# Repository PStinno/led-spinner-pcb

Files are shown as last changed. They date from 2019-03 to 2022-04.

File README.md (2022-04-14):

# led-spinner-pcb
My first two layer PCB, spinning LED effect with no micro-controller or code.



The circuit consists of two 4017 decade counters, connected together to create sixteen sequential outputs. The outputs progress on each clock cycle and loop back to the beginning when the end is reached. Each output is connected to an LED on the perimeter of the PCB. The clock input is connected to a 555 timer IC in an astable configuration. This generates a continous square wave, causing the progression of the outputs and the spinning effect. The momentary push button completes the circuit, so it is only powered when the button is held down.

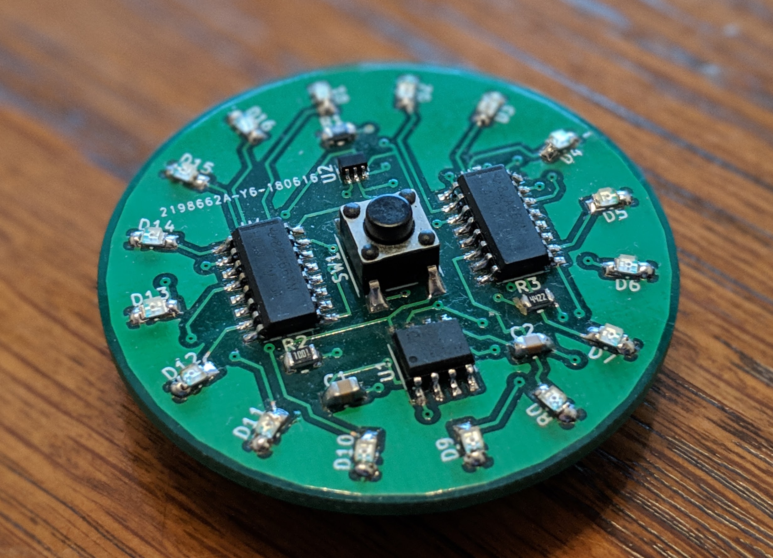
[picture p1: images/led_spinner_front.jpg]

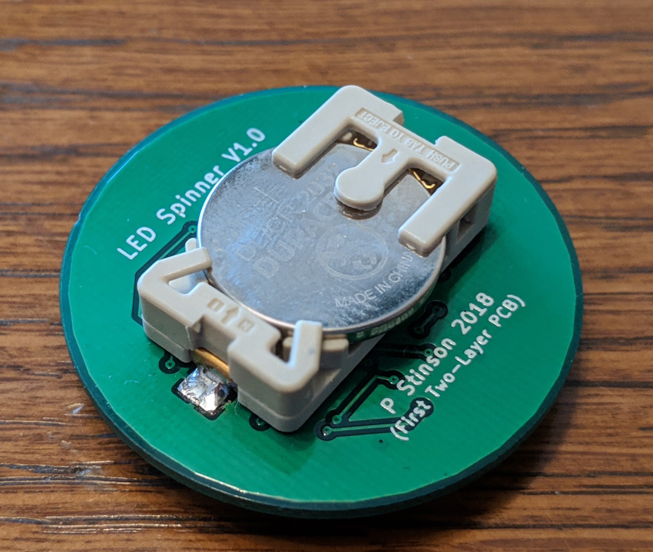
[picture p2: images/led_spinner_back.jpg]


[][cc-by-sa]

[cc-by-sa]: http://creativecommons.org/licenses/by-sa/4.0/
[cc-by-sa-image]: https://licensebuttons.net/l/by-sa/4.0/88x31.png
[cc-by-sa-shield]: https://img.shields.io/badge/License-CC%20BY--SA%204.0-lightgrey.svg

This work is licensed under a [Creative Commons Attribution-ShareAlike 4.0 International License][cc-by-sa].

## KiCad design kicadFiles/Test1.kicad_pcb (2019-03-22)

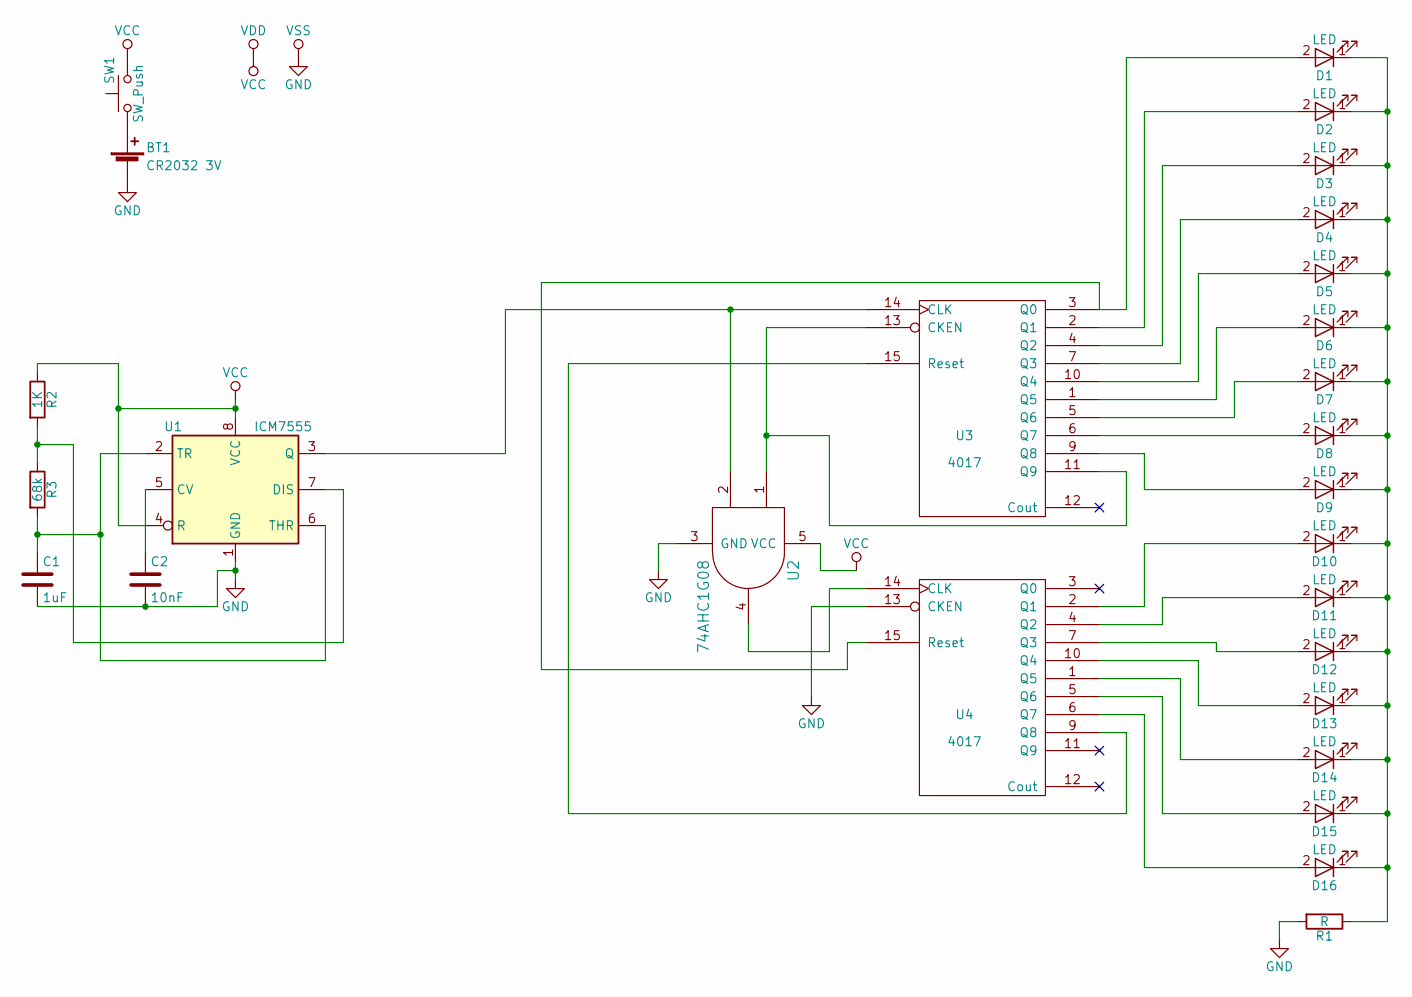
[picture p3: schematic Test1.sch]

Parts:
BT1: CR2032 3V; MPD_BA2032SM
C1: 1uF; C_0805
C2: 10nF; C_0805
D1, D2, D3, D4, D5, D6, D7, D8, D9, D10, D11, D12, D13, D14, D15, D16: LED; LED_0805
R1: R; R_0805
R2: 1K; R_0805
R3: 68k; R_0805
SW1: SW_Push; SW_SPST_PTS645
U1: ICM7555; SOIC-8_3.9x4.9mm_Pitch1.27mm
U2: 74AHC1G08; SOT-353_SC-70-5
U3, U4: 4017; SOIC-16_3.9x9.9mm_Pitch1.27mm

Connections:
GND: BT1.2 (-), C1.2, C2.2, R1.2, U1.1 (GND), U2.3 (GND), U3.8 (VSS), U4.8 (VSS), U4.13 (CKEN)
unnamed: BT1.1 (+), SW1.1
unnamed: C1.1, R3.2, U1.2 (TR), U1.6 (THR)
unnamed: C2.1, U1.5 (CV)
unnamed: D1.1 (K), D2.1 (K), D3.1 (K), D4.1 (K), D5.1 (K), D6.1 (K), D7.1 (K), D8.1 (K), D9.1 (K), D10.1 (K), D11.1 (K), D12.1 (K), D13.1 (K), D14.1 (K), D15.1 (K), D16.1 (K), R1.1
unnamed: D1.2 (A), U3.3 (Q0), U4.15 (Reset)
unnamed: D2.2 (A), U3.2 (Q1)
unnamed: D3.2 (A), U3.4 (Q2)
unnamed: D4.2 (A), U3.7 (Q3)
unnamed: D5.2 (A), U3.10 (Q4)
unnamed: D6.2 (A), U3.1 (Q5)
unnamed: D7.2 (A), U3.5 (Q6)
unnamed: D8.2 (A), U3.6 (Q7)
unnamed: D9.2 (A), U3.9 (Q8)
unnamed: D10.2 (A), U4.2 (Q1)
unnamed: D11.2 (A), U4.4 (Q2)
unnamed: D12.2 (A), U4.7 (Q3)
unnamed: D13.2 (A), U4.10 (Q4)
unnamed: D14.2 (A), U4.1 (Q5)
unnamed: D15.2 (A), U4.5 (Q6)
unnamed: D16.2 (A), U4.6 (Q7)
unnamed: R2.2, R3.1, U1.7 (DIS)
unnamed: U1.3 (Q), U2.2, U3.14 (CLK)
unnamed: U2.1, U3.11 (Q9), U3.13 (CKEN)
unnamed: U2.4, U4.14 (CLK)
unnamed: U3.15 (Reset), U4.9 (Q8)
VCC: R2.1, SW1.2, U1.4 (R), U1.8 (VCC), U2.5 (VCC), U3.16 (VDD), U4.16 (VDD)

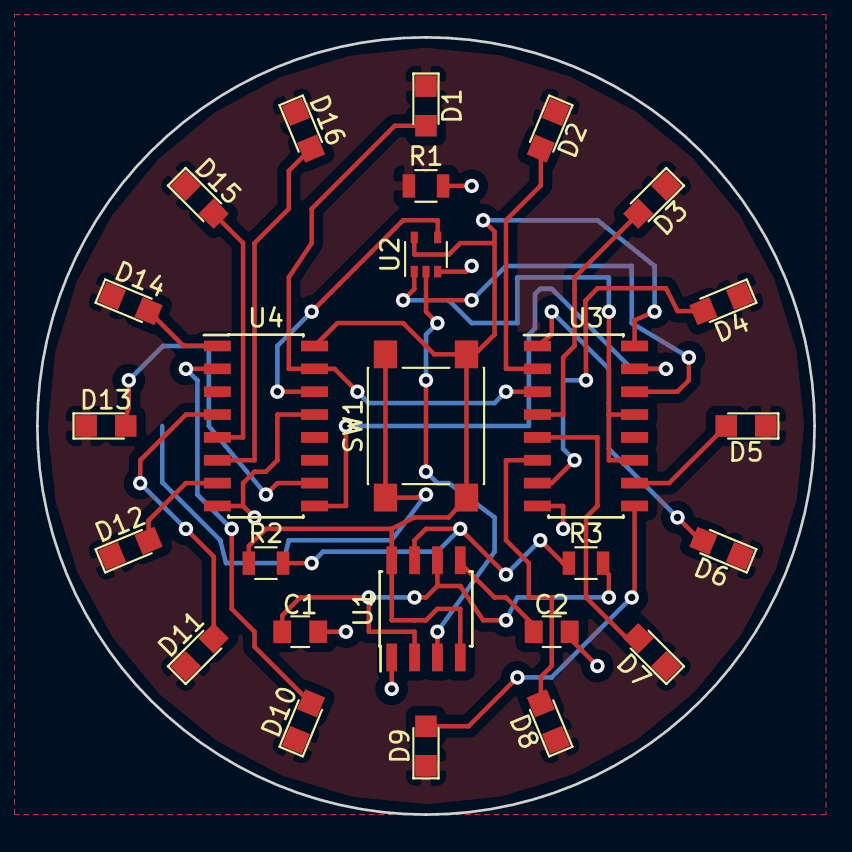
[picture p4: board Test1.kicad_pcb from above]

Board: 2 copper layers, 43.2 x 43.2 mm, 27 parts (1 on the bottom side), 27 nets.

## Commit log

2019-03-22 Update README, add basic circuit description
2019-03-22 Add kicad design files
    [Test1-B.Cu.gbl, Test1-B.Mask.gbs, Test1-B.SilkS.gbo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]
2019-03-22 Update circuit description

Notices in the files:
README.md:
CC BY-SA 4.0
